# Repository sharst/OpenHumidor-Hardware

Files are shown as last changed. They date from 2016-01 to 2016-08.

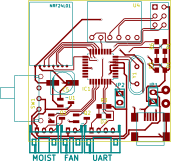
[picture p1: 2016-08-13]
CircuitBoards/openhum6-mega/gerber/front.png

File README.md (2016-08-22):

# OpenHumidor-Hardware
KiCad files of the OpenHumidor sensor PCB.
Files for 3D-printed humidifier parts, enclosures of the sensor board, etc.

Copyright 2016 Simon Harst

These files are licenced under the GPL v3 Licence, see LICENCE file.

The sensor PCB

I have included former versions of the PCB in separate folders. 

Versions 2 and 3 were created using the free version of EAGLE. Since version 4, boards are created with KICAD. 

## Ordering PCBs
The current version of the board is v0.6-mega. I'm currently testing all functions but minor bugs might still occur. If you're interested in trying out this project, you should consider contacting me.

So far, I have only ordered with two companies: 
* [PCB-pool](www.pcb-pool.de), located in Germany, the cheapest option takes about 2 weeks incl. shipping, you can directly upload the .kicad_pcb-file. 
* [Seeed Studio](http://www.seeedstudio.com/service/index.php?r=pcb), located in China and a lot cheaper (~14Euros for 10 pcbs). Takes about a month including shipping. You need to upload the .zip-file that's included in the gerber/ folder.

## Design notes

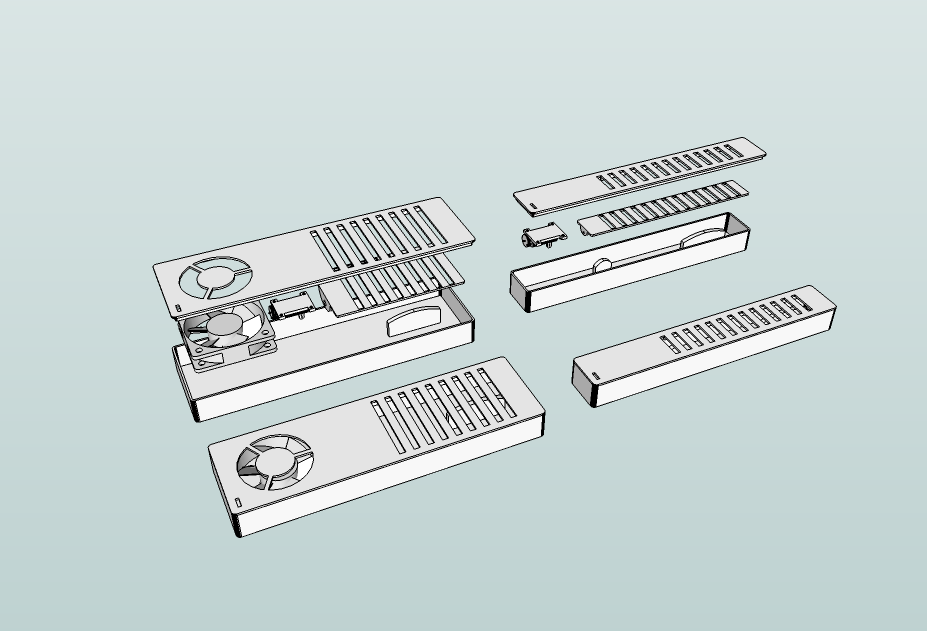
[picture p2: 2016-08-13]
Humidifier/humidifier_3dprint_overview.png

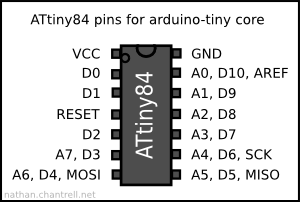
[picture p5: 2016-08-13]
datasheets_pinouts/attiny84-arduinocore.png

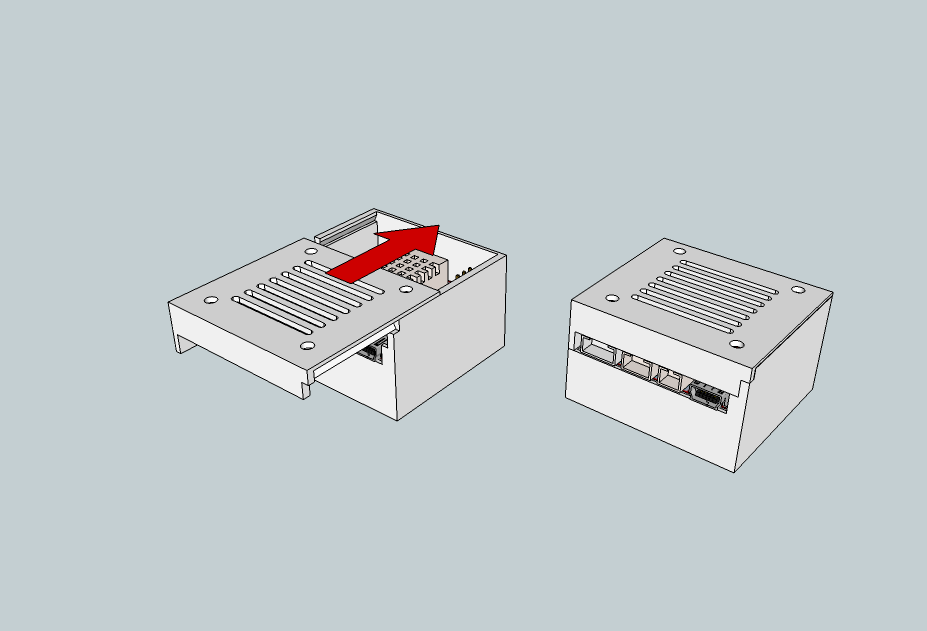
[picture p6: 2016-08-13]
BoardEnclosure/board-enclosure.png

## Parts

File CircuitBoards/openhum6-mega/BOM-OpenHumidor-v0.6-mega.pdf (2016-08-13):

(Akku BST-38) | 3.85 | 1 | 3.85 | ebay

## BOM OpenHumidor v0.6-mega

Piece Number | Decription | Price / unit | Amount | Total Price | Source | order number | Alternative Source | Alt. order # | Alt. Price | Notes
IC1 | ATMEGA328P-A | 3.2 | 1 | 3.2 | reichelt | ATMEGA 328P-AU | aliexpress | ATMEGA328 | 1.07
R1 | 470 O | 0.103 | 1 | 0.103 | reichelt | SMD-0805 470 | farnell | 9333258
R2 | 2k | 0.103 | 2 | 0.206 | reichelt N/A | | farnell | 9332766
R3 | 1k | 0.103 | 1 | 0.103 | reichelt | SMD-0805 1,00K | farnell | 9332383
R6 | 100 O | 0.103 | 1 | 0.103 | reichelt | SMD-0805 100
U1 | MCP1700 | 0.386 | 1 | 0.386 | farnell | 1296592 | reichelt | MCP 1703-3302CB
U2 | MCP73831 | 0.563 | 1 | 0.563 | farnell | 1840935
U3 | Nrf24L01 Mini | 1.16 | 1 | 1.16 | ebay | Nrf24L01 Mini
U4 | BME280 | 4.5 | 1 | 4.5 | ebay | 282083076305 | ebay (from Germany | 17224747660 | | BMP280 does NOT work (has no humidity sensor)
D1 | LED RED | 0.08 | 1 | 0.08 | reichelt | SMD-LED 0805 RT | farnell | 2090236
D2 | Fast switching diode | 0.04 | 1 | 0.04 | reichelt | TS 4148-0805
D3 | LED BLUE | 0.194 | 1 | 0.194 | reichelt | SMD-LED 0805 BL | farnell | 2217974
C1, C2 | 4.7uF | 0.05 | 2 | 0.1 | reichelt | X5R-G0805 4,7 | farnell | 2426962
C3 | 100nF | 0.04 | 1 | 0.04 | reichelt | X7R-G0805 100N
C5 | 100uF | 0.2 | 1 | 0.2 | reichelt | VF 100/6,3 P-C
C4, C6 | 22pF | 0.04 | 2 | 0.08 | reichelt | NPO-G0805 22P | farnell | 2497023
Q1, Q2 | 2n7002 JFET | 0.04 | 2 | 0.08 | reichelt | 2N 7002 SMD
CON1 | Mini USB Connector | 0.27 | 1 | 0.27 | reichelt | USB BWM SMD | farnell | 1125348
P1 | Header 6-PIN | 0.13 | 1 | 0.13 | reichelt | MPE 087-2-006 | farnell | 1622578
P3 | JST-PH4 | 0.139 | 1 | 0.139 | farnell | 9492488
P4 | JST-PH3 | 0.152 | 2 | 0.304 | farnell | 9491910
P5 | JST-PH2 | 0.11 | 1 | 0.11 | farnell | 9491902
SW1 | ON/OFF-Switch | 0.109 | 1 | 0.109 | ebay | SS12F21
Y1 | Quarz 16MHz | 0.28 | 1 | 0.28 | reichelt | 16,0000-HC49U-S | farnell | 2509297
Board Manufacture | | 0.99 | 1 | 0.99 | seeedstudio
JP1, JP2 | Jumper
| | | Total | 13.47

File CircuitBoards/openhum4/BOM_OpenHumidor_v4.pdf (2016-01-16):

(Akku BST-38) | ebay | 3.9 | 0 | 3.9

## BOM OpenHumidor v4

Piece Number | Decription | Source | Price / unit | Amount | Total Price | order number | alternative
IC1 | ATTINY84-SSU | reichelt | 1.5 | 1 | 1.5 | ATTINY84-SSU
IC2 | DHT22 | ebay | 2.88 | 1 | 2.88
R1 | 470 O | reichelt | 0.103 | 1 | 0.103 | SMD 1/4W 470
R2 | 2k | reichelt | 0.103 | 2 | 0.206 | SMD 1/4W 2,0K
R6, R7 | 100 O | reichelt | 0.103 | 2 | 0.206 | SMD 1/4W 100
U1 | MCP1700 | farnell | 0.386 | 1 | 0.386 | 1296592
U2 | MCP73831 | farnell | 0.563 | 1 | 0.563 | 1840935
U3 | Nrf24L01 Mini | ebay | 0.82 | 1 | 0.82
D1 | LED GREEN | farnell | 0.0748 | 1 | 0.0748 | 2099247
D3 | LED BLUE | farnell | 0.194 | 1 | 0.194 | 2217976
C1, C2 | 4.7uF | farnell | 0.0441 | 2 | 0.0882 | 9227938
C3, C4 | 100uF | farnell | 0.78 | 1 | 0.78 | 2354127
Q1, Q2 | 2n7002 JFET | farnell | 0.051 | 2 | 0.102 | 1764535
CON1 | Mini USB Connector | reichelt | 0.27 | 1 | 0.27 | USB BWM SMD | Farnell 1125348
P1 | Header 6-PIN | reichelt | 0.13 | 1 | 0.13 | MPE 087-2-006 | Farnell 1622578 oder 10stck 1022231
P3, P4 | JST-PH3 | farnell | 0.152 | 2 | 0.304 | 9491910
P5 | JST-PH2 | farnell | 0.11 | 1 | 0.11 | 9491902
Board Manufacture | | seeedstudio | 0.99 | 1 | 0.99
| | | | Gesamt | 9.707

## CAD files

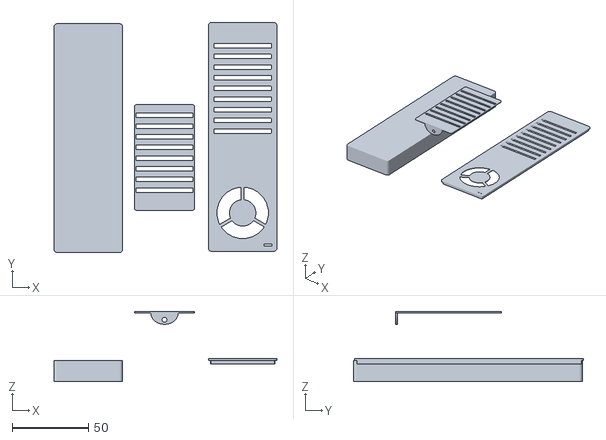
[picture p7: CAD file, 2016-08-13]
Humidifier/humidifier_3dprint_large.stl
146.2 x 150.8 x 46.1

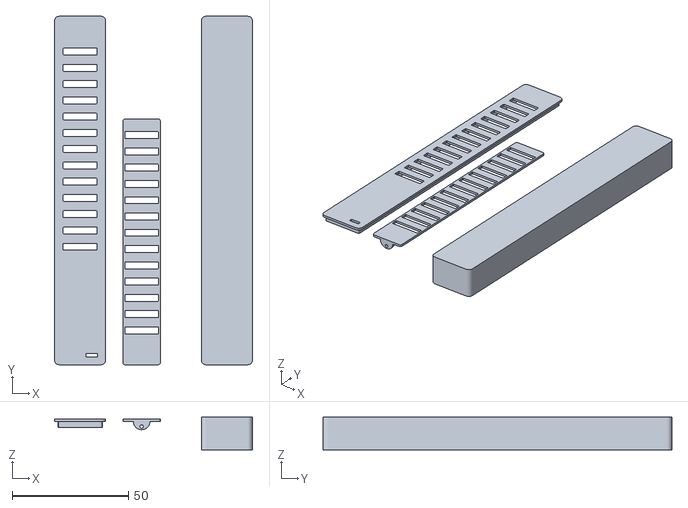
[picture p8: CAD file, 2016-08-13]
Humidifier/humidifier_3dprint_small.stl
85.2 x 150.0 x 14.0

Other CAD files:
BaseStation/BaseStation.skp
BoardEnclosure/board-enclosure.skp
BoardEnclosure/board-enclosure_v06.skp
Humidifier/humidifier_fabtools.skp
Humidifier/humidifier_fabtools_stepper.skp
Humidifier/humidifiers_3dprint.skp

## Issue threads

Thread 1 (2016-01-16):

Fan mount on enclosure

sharst, 2016-01-16:
The enclosure should have a mount for a 5V, 40mm fan that can be enabled before checking the humidity.

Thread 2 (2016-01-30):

Q1 drain pin isn't pulled up nicely when gate is pulled low

sharst, 2016-01-30:

sharst, 2016-01-30:
This seems to be related to the DHT22 since everything works on a board where the DHT isn't mounted

sharst, 2016-01-30:
Was a software bug: Since the DHT-Data pin is pulled high by hardware, sinks a lot of current when pulled low. This happened in enable_io(). Fixed.

Closed 2016-01-30.

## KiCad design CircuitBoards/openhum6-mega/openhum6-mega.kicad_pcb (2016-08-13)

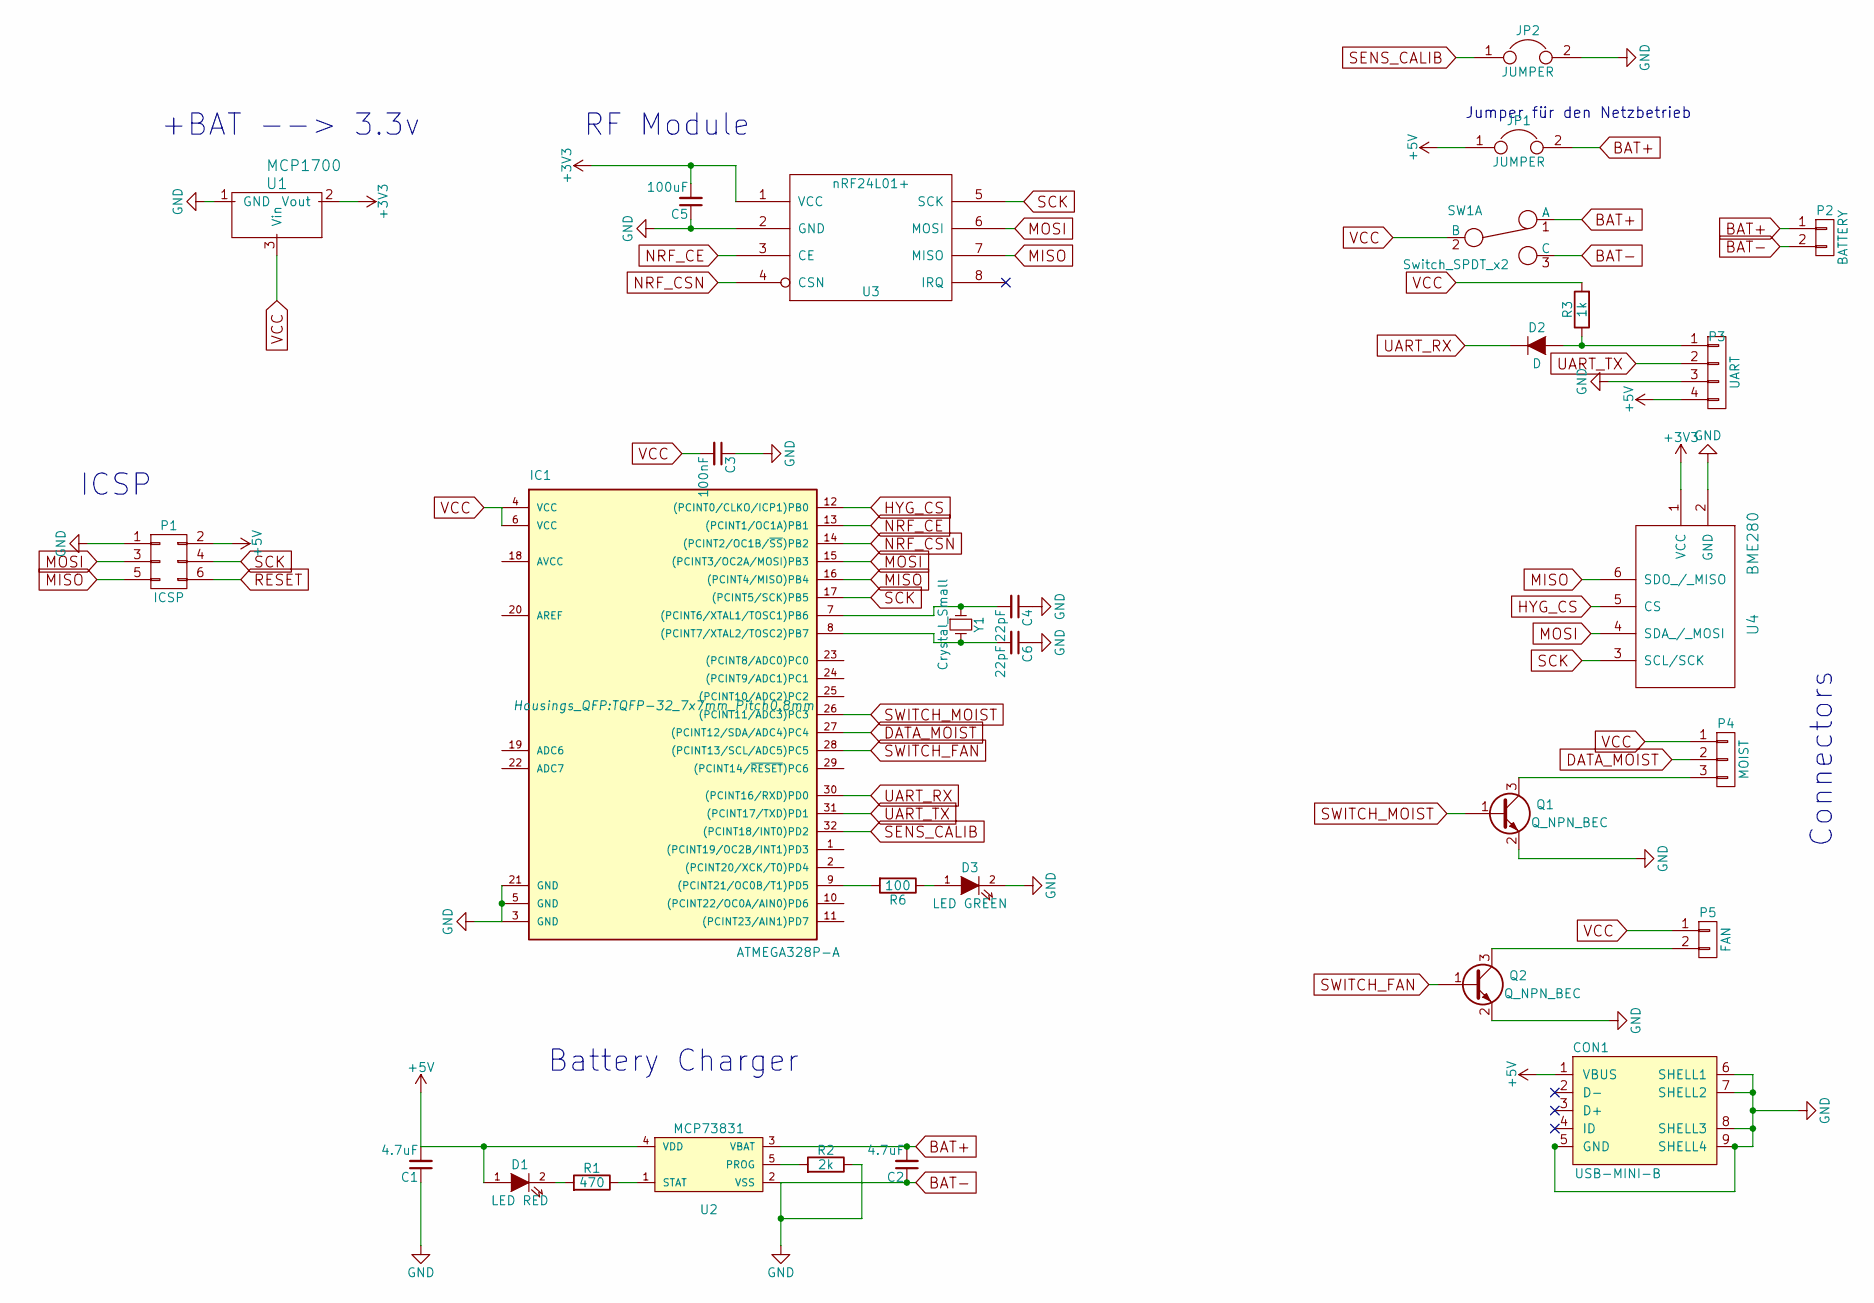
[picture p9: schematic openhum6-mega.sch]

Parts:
C1, C2: 4.7uF; R_0805_HandSoldering
C3: 100nF; R_0805_HandSoldering
C4, C6: 22pF; R_0805_HandSoldering
C5: 100uF; c_elec_6.3x5.3
CON1: USB-MINI-B; USB_Mini-B
D1: LED RED; R_0805_HandSoldering
D2: D; R_0805_HandSoldering
D3: LED GREEN; R_0805_HandSoldering
IC1: ATMEGA328P-A; TQFP-32_7x7mm_Pitch0.8mm
JP1, JP2: JUMPER; pin_strip_2
P1: ICSP; 2x3_pin_header
P2: BATTERY; solderpad2x
P3: UART; s4b-ph-kl
P4: MOIST; s3b-ph-kl
P5: FAN; s2b-ph-kl
Q1, Q2: Q_NPN_BEC; SOT-23_Handsoldering
R1: 470; R_0805_HandSoldering
R2: 2k; R_0805_HandSoldering
R3: 1k; R_0805_HandSoldering
R6: 100; R_0805_HandSoldering
SW1: Switch_SPDT_x2; SS12F23
U1: MCP1700; SOT-23_Handsoldering
U2: MCP73831; SOT-23-5_handsoldering
U3: nRF24L01+; nrf24l01_mini
U4: BME280; BMP280
Y1: Crystal_Small; Crystal_HC49-U_Vertical

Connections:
+3V3: C5.2, U1.2 (Vout), U3.1 (VCC), U4.1 (VCC)
+5V: C1.2, CON1.1 (VBUS), D1.1 (A), JP1.1, P1.2, P3.4, U2.4 (VDD)
BAT+: C2.2, JP1.2, P2.1, SW1.1 (A), U2.3 (VBAT)
BAT-: C1.1, C2.1, C3.1, C4.1, C5.1, C6.1, CON1.5 (GND), CON1.6 (SHELL1), CON1.7 (SHELL2), CON1.8 (SHELL3), CON1.9 (SHELL4), D3.2 (K), IC1.3 (GND), IC1.5 (GND), IC1.21 (GND), JP2.2, P1.1, P2.2, P3.3, Q1.2 (E), Q2.2 (E), R2.1, SW1.3 (C), U1.1 (GND), U2.2 (VSS), U3.2 (GND), U4.2 (GND)
DATA_MOIST: IC1.27 ((PCINT12/SDA/ADC4)PC4), P4.2
HYG_CS: IC1.12 ((PCINT0/CLKO/ICP1)PB0), U4.5 (CS)
MISO: IC1.16 ((PCINT4/MISO)PB4), P1.5, U3.7 (MISO), U4.6 (SDO_/_MISO)
MOSI: IC1.15 ((PCINT3/OC2A/MOSI)PB3), P1.3, U3.6 (MOSI), U4.4 (SDA_/_MOSI)
NRF_CE: IC1.13 ((PCINT1/OC1A)PB1), U3.3 (CE)
NRF_CSN: IC1.14 ((PCINT2/OC1B/~SS~)PB2), U3.4 (CSN)
unnamed: C4.2, IC1.7 ((PCINT6/XTAL1/TOSC1)PB6), Y1.1
unnamed: C6.2, IC1.8 ((PCINT7/XTAL2/TOSC2)PB7), Y1.2
unnamed: D1.2 (K), R1.2
unnamed: D2.2 (A), P3.1, R3.1
unnamed: D3.1 (A), R6.1
unnamed: IC1.9 ((PCINT21/OC0B/T1)PD5), R6.2
unnamed: P4.3, Q1.3 (C)
unnamed: P5.2, Q2.3 (C)
unnamed: R1.1, U2.1 (STAT)
unnamed: R2.2, U2.5 (PROG)
RESET: IC1.29 ((PCINT14/~RESET~)PC6), P1.6
SCK: IC1.17 ((PCINT5/SCK)PB5), P1.4, U3.5 (SCK), U4.3 (SCL/SCK)
SENS_CALIB: IC1.32 ((PCINT18/INT0)PD2), JP2.1
SWITCH_FAN: IC1.28 ((PCINT13/SCL/ADC5)PC5), Q2.1 (B)
SWITCH_MOIST: IC1.26 ((PCINT11/ADC3)PC3), Q1.1 (B)
UART_RX: D2.1 (K), IC1.30 ((PCINT16/RXD)PD0)
UART_TX: IC1.31 ((PCINT17/TXD)PD1), P3.2
VCC: C3.2, IC1.4 (VCC), IC1.6 (VCC), P4.1, P5.1, R3.2, SW1.2 (B), U1.3 (Vin)

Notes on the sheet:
Battery Charger
ICSP
+BAT --> 3.3v
RF Module
Connectors
Jumper für den Netzbetrieb

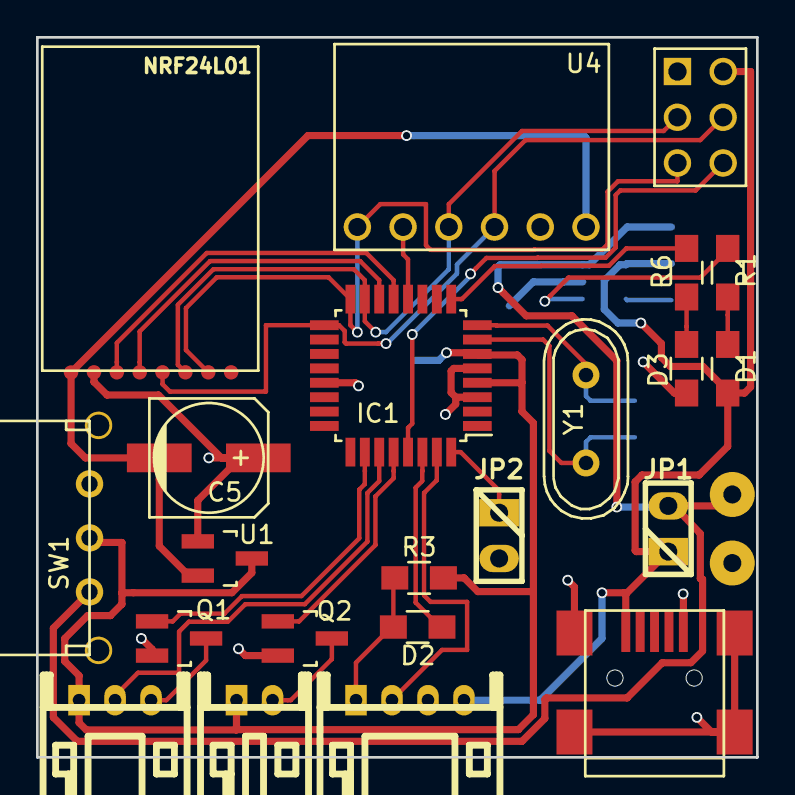
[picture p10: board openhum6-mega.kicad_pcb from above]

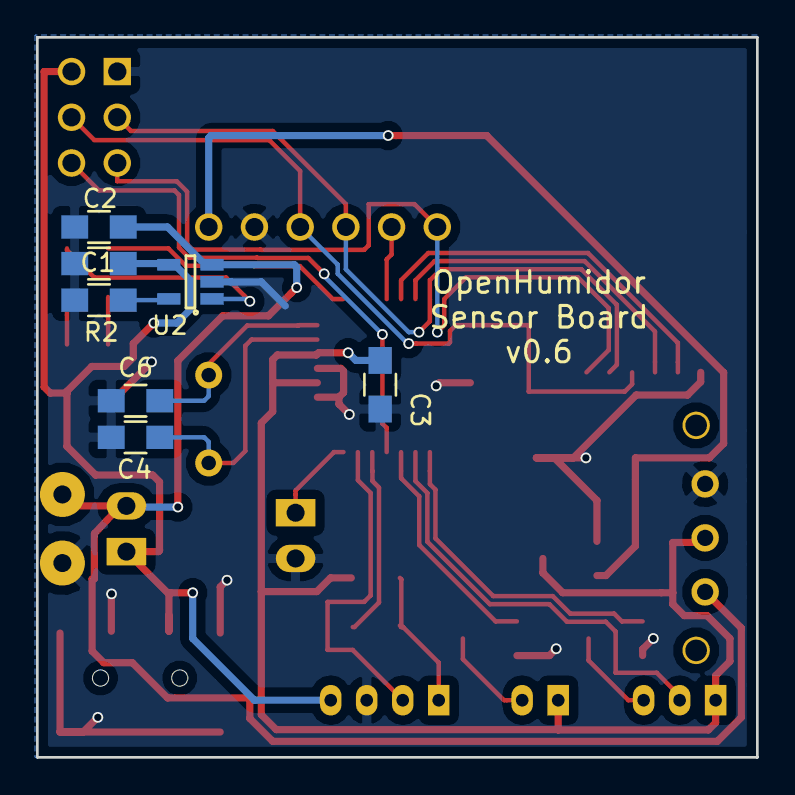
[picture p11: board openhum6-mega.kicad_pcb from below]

Board: 2 copper layers, 40.0 x 40.0 mm, 27 parts (7 on the bottom side), 24 nets.

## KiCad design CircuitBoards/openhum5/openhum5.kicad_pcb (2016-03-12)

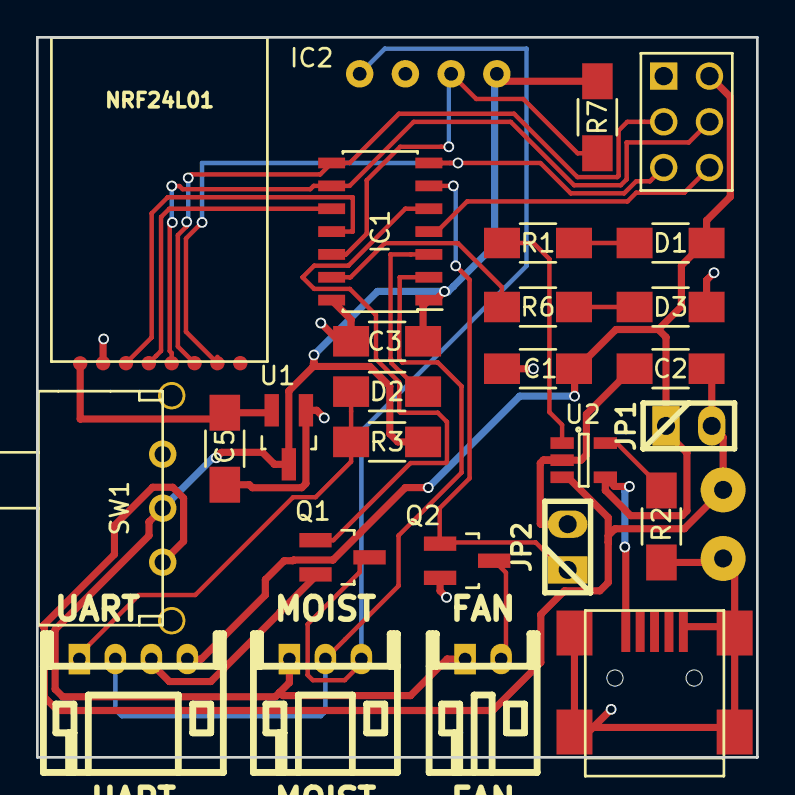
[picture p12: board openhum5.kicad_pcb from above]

Board: 2 copper layers, 40.0 x 40.0 mm, 28 parts (0 on the bottom side), 24 nets.

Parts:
C1, C2: 4.7uF; R_1206_HandSoldering
C3, C5: 100uF; R_1206_HandSoldering
CON1: USB-MINI-B; USB_Mini-B
D1: LED RED; R_1206_HandSoldering
D2: D; R_1206_HandSoldering
D3: LED GREEN; R_1206_HandSoldering
FAN: FAN; s2b-ph-kl
IC1: ATTINY84A-SS; SOIC-14_3.9x8.7mm_Pitch1.27mm
IC2: DHT22
JP1, JP2: JUMPER; pin_strip_2
MOIST: MOIST; s3b-ph-kl
P1: ICSP; 2x3_pin_header
P2: BATTERY; solderpad2x
Q1, Q2: Q_NPN_BEC; SOT-23_Handsoldering
R1: 470; R_1206_HandSoldering
R2: 2k; R_1206_HandSoldering
R3: 1k; R_1206_HandSoldering
R6, R7: 100; R_1206_HandSoldering
SW1: Switch_SPDT_x2; SS12F23
U1: MCP1700; SOT-23_Handsoldering
U2: MCP73831; SOT-23-5_handsoldering
U3: nRF24L01+; nrf24l01_mini
UART: UART; s4b-ph-kl

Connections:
+3V3: C5.2, U1.2, U3.1
+5V: C1.2, CON1.1, D1.1, JP1.1, P1.2, U2.4, UART.4
BAT+: C2.2, JP1.2, P2.1, SW1.1, U2.3
BAT-: C1.1, C2.1, C3.2, C5.1, CON1.5, CON1.6, D3.2, IC1.14, JP2.2, P1.1, P2.2, Q1.2, Q2.2, R2.1, SW1.3, U1.1, U2.2, U3.2, UART.3
DATA_HYGRO: IC1.12, IC2.2, R7.1
DATA_MOIST: IC1.2, MOIST.2, UART.2
MISO: IC1.7, P1.5, U3.7
MOSI: IC1.8, P1.3, U3.6
NRF_CE: IC1.11, U3.3
NRF_CSN: IC1.10, U3.4
unnamed: D1.2, R1.2
unnamed: D2.2, R3.1, UART.1
unnamed: D3.1, R6.1
unnamed: IC1.13, R6.2
unnamed: IC2.4, MOIST.3, Q1.3
unnamed: FAN.2, Q2.3
unnamed: R1.1, U2.1
unnamed: R2.2, U2.5
RESET: IC1.4, P1.6
SCK: IC1.9, P1.4, U3.5
SENS_CALIB: IC1.6, JP2.1, Q2.1
SWITCH_MOIST: IC1.5, Q1.1
UART_RX: D2.1, IC1.3
VCC: C3.1, FAN.1, IC1.1, IC2.1, MOIST.1, R3.2, R7.2, SW1.2, U1.3

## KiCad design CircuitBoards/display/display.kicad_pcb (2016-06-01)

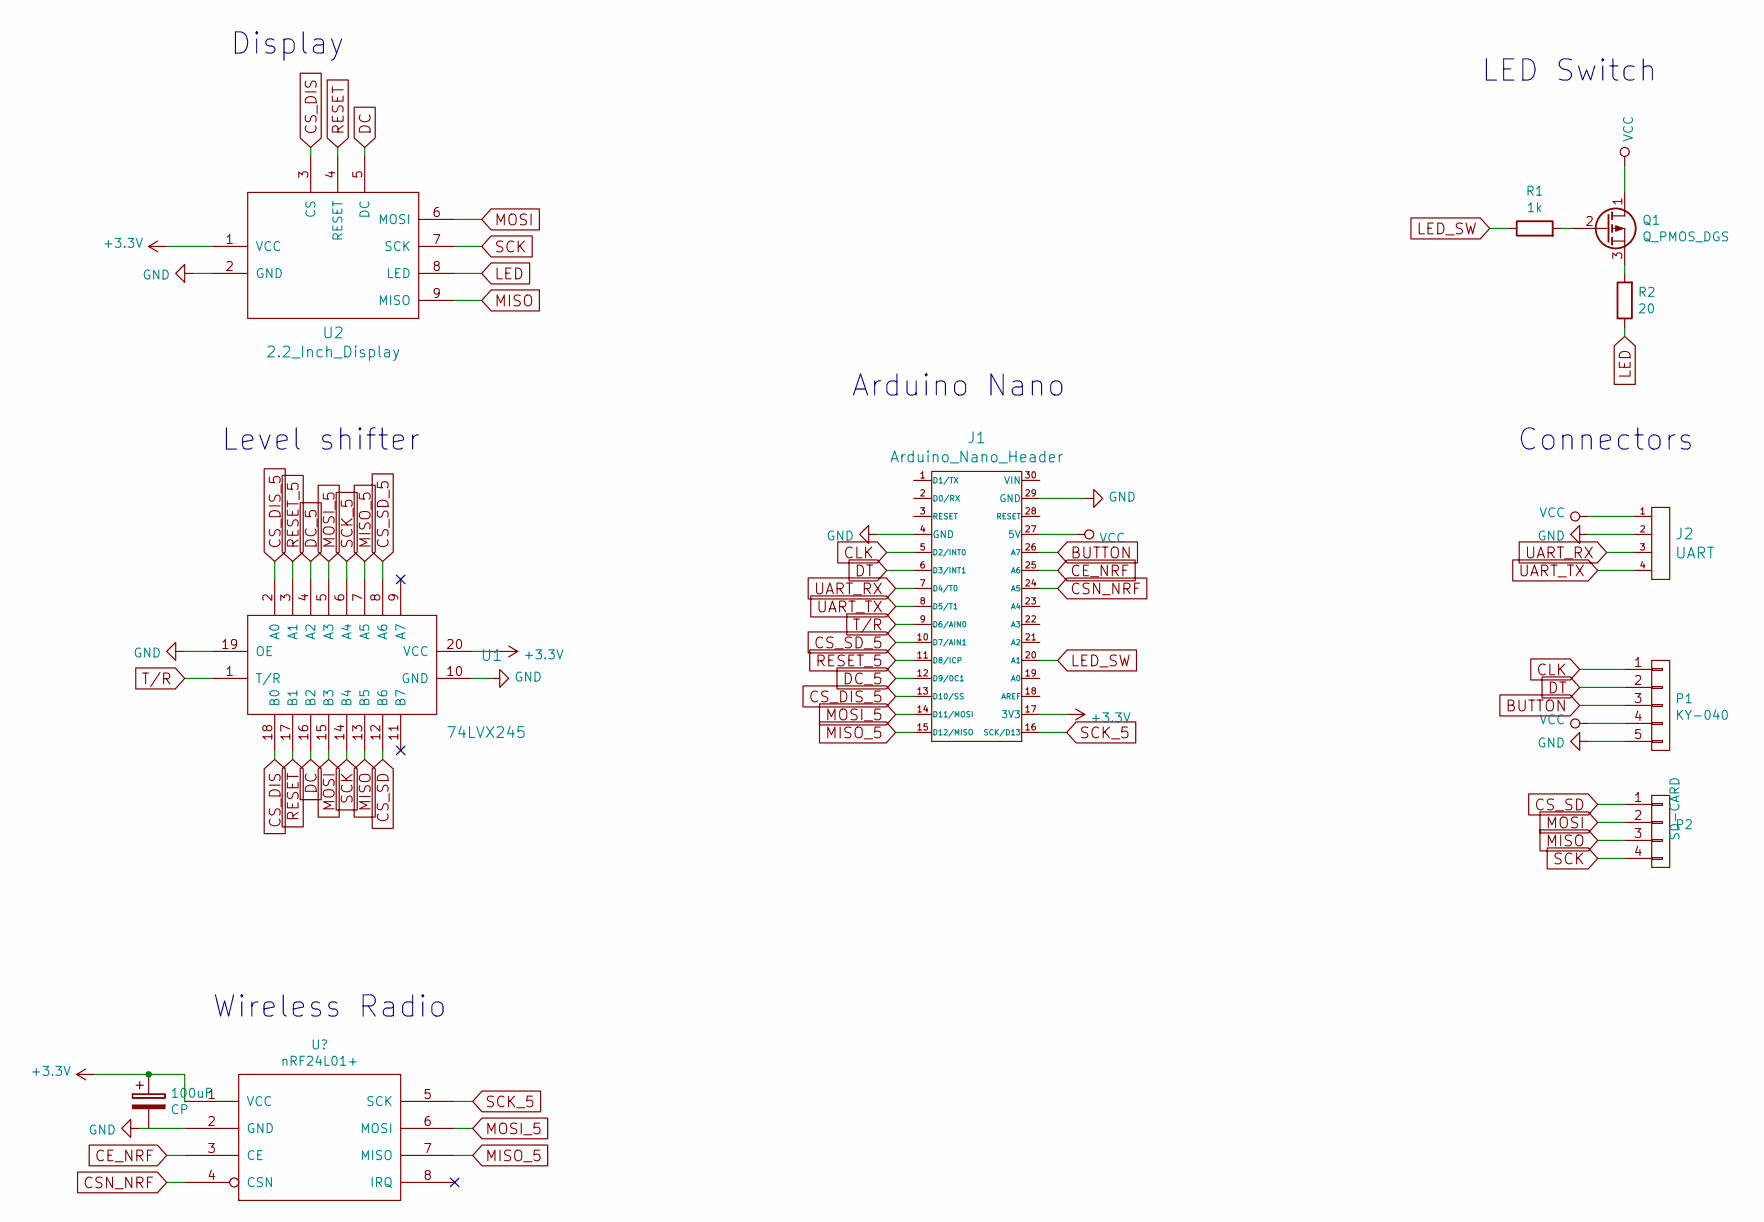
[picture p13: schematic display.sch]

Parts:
100uF: CP
J1: Arduino_Nano_Header; arduino_nano_header
J2: UART; b4b-ph-kl
P1: KY-040; b5b-ph-kl
P2: SD-CARD; b4b-ph-kl
Q1: Q_PMOS_DGS; SOT-23_Handsoldering
R1: 1k; R_1206_HandSoldering
R2: 20; R_1206_HandSoldering
U1: 74LVX245; TSSOP20
U2: 2.2_Inch_Display; 2_2inch_display

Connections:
+3V3: 100uF.1, J1.17 (3V3), U1.20 (VCC), U2.1 (VCC)
BUTTON: J1.26 (A7), P1.3
CLK: J1.5 (D2/INT0), P1.1
CS_DIS: U1.18 (B0), U2.3 (CS)
CS_DIS_5: J1.13 (D10/SS), U1.2 (A0)
CS_SD: P2.1, U1.12 (B6)
CS_SD_5: J1.10 (D7/AIN1), U1.8 (A6)
DC: U1.16 (B2), U2.5 (DC)
DC_5: J1.12 (D9/0C1), U1.4 (A2)
DT: J1.6 (D3/INT1), P1.2
GND: J1.4 (GND), J1.29 (GND), J2.2, P1.5, U1.10 (GND), U1.19 (OE), U2.2 (GND)
LED: R2.1, U2.8 (LED)
LED_SW: J1.20 (A1), R1.1
MISO: P2.3, U1.13 (B5), U2.9 (MISO)
MISO_5: J1.15 (D12/MISO), U1.7 (A5)
MOSI: P2.2, U1.15 (B3), U2.6 (MOSI)
MOSI_5: J1.14 (D11/MOSI), U1.5 (A3)
unnamed: Q1.2 (G), R1.2
unnamed: Q1.3 (S), R2.2
RESET: U1.17 (B1), U2.4 (RESET)
RESET_5: J1.11 (D8/ICP), U1.3 (A1)
SCK: P2.4, U1.14 (B4), U2.7 (SCK)
SCK_5: J1.16 (SCK/D13), U1.6 (A4)
T/R: J1.9 (D6/AIN0), U1.1 (T/R)
UART_RX: J1.7 (D4/T0), J2.3
UART_TX: J1.8 (D5/T1), J2.4
VCC: J1.27 (5V), J2.1, P1.4, Q1.1 (D)

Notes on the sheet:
Arduino Nano
Display
Level shifter
LED Switch
Connectors
Wireless Radio

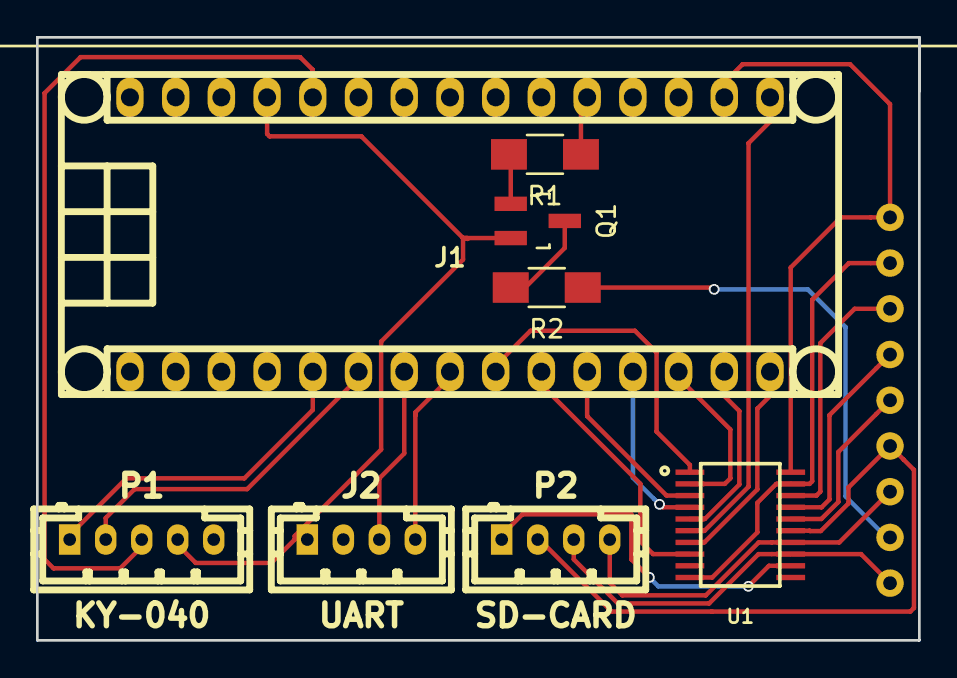
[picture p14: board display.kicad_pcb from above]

Board: 2 copper layers, 49.0 x 33.5 mm, 9 parts (0 on the bottom side), 27 nets.

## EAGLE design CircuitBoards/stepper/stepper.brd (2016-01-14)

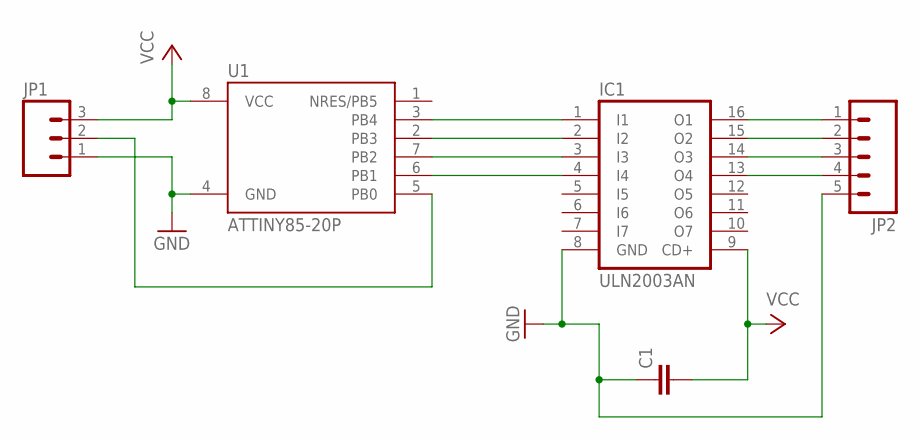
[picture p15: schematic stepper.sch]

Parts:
C1: C-EU025-025X050; C025-025X050
IC1: ULN2003AN; DIL16
JP1: M03JST-PTH; JST-3-PTH
JP2: M05PTH_LONGPADS; 1X05_LONGPADS
U1: ATTINY85-20P; PDIP08_300MIL

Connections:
GND: C1.1, IC1.8 (GND), JP1.1, JP2.5, U1.4 (GND)
unnamed: IC1.1 (I1), U1.3 (PB4)
unnamed: IC1.2 (I2), U1.2 (PB3)
unnamed: IC1.3 (I3), U1.7 (PB2)
unnamed: IC1.4 (I4), U1.6 (PB1)
unnamed: JP1.2, U1.5 (PB0)
unnamed: IC1.16 (O1), JP2.1
unnamed: IC1.15 (O2), JP2.2
unnamed: IC1.14 (O3), JP2.3
unnamed: IC1.13 (O4), JP2.4
VCC: C1.2, IC1.9 (CD+), JP1.3, U1.8 (VCC)

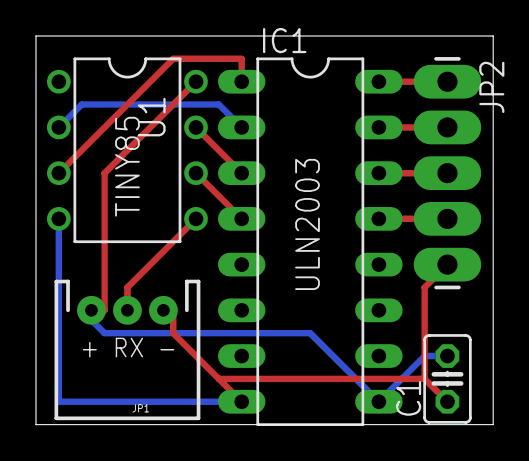
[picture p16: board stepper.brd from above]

Board: 2 copper layers, 25.4 x 21.6 mm, 5 parts (0 on the bottom side), 11 nets.

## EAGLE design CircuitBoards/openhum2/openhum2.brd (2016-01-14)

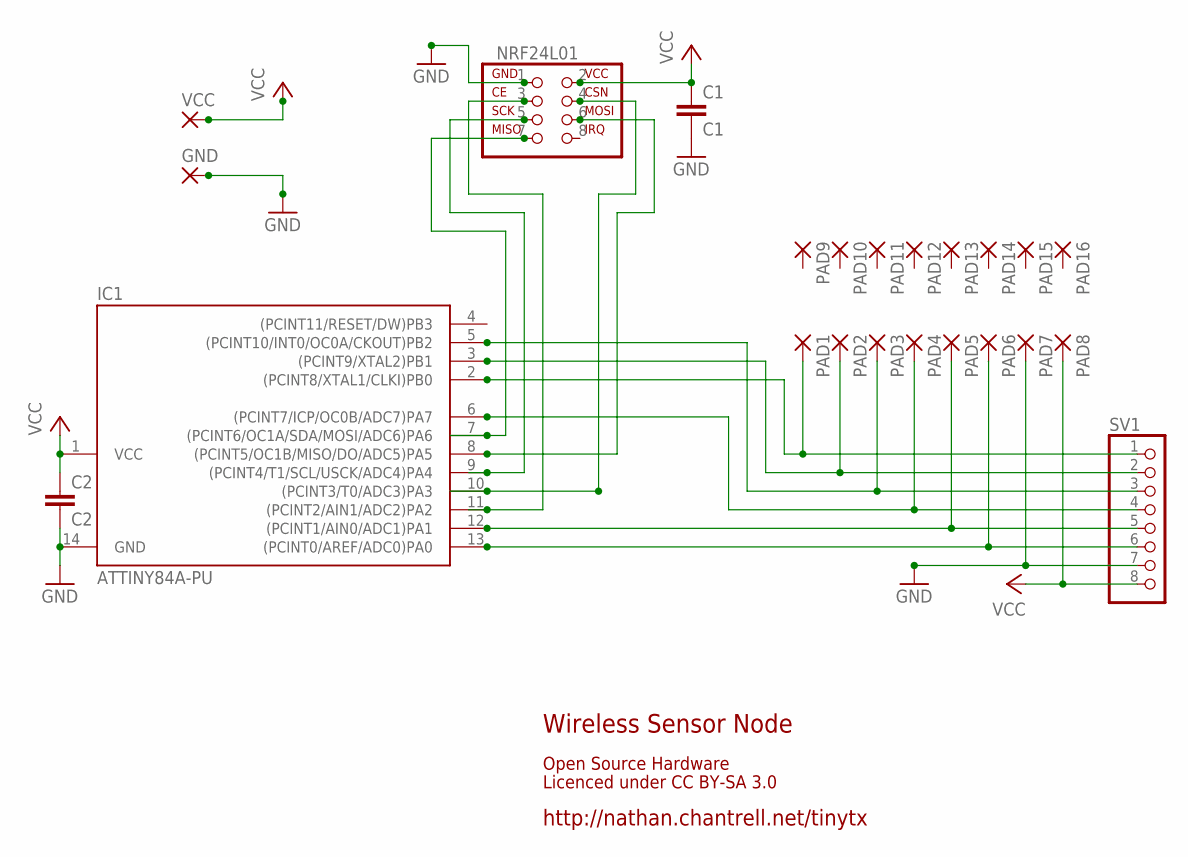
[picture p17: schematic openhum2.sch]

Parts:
C1: C1; C025-025X050
C2: C2; C025-025X050
GND: 2,15/1,0
IC1: ATTINY84A-PU; DIL14
NRF24L01: NRF24L01+
PAD1, PAD2, PAD3, PAD4, PAD5, PAD6, PAD7, PAD8, PAD9, PAD10, PAD11, PAD12, PAD13, PAD14, PAD15, PAD16: 1,6/0,9
SV1: PINHD-1X8; 1X08
VCC: 2,15/1,0

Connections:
GND: C1.2, C2.2, GND.1, IC1.14 (GND), NRF24L01.1, PAD7.1, SV1.7
unnamed: IC1.11 ((PCINT2/AIN1/ADC2)PA2), NRF24L01.3
unnamed: IC1.10 ((PCINT3/T0/ADC3)PA3), NRF24L01.4
unnamed: IC1.9 ((PCINT4/T1/SCL/USCK/ADC4)PA4), NRF24L01.5
unnamed: IC1.7 ((PCINT6/OC1A/SDA/MOSI/ADC6)PA6), NRF24L01.7
unnamed: IC1.5 ((PCINT10/INT0/OC0A/CKOUT)PB2), PAD3.1, SV1.3
unnamed: IC1.3 ((PCINT9/XTAL2)PB1), PAD2.1, SV1.2
unnamed: IC1.13 ((PCINT0/AREF/ADC0)PA0), PAD6.1, SV1.6
unnamed: IC1.12 ((PCINT1/AIN0/ADC1)PA1), PAD5.1, SV1.5
unnamed: IC1.8 ((PCINT5/OC1B/MISO/DO/ADC5)PA5), NRF24L01.6
unnamed: IC1.2 ((PCINT8/XTAL1/CLKI)PB0), PAD1.1, SV1.1
unnamed: IC1.6 ((PCINT7/ICP/OC0B/ADC7)PA7), PAD4.1, SV1.4
VCC: C1.1, C2.1, IC1.1 (VCC), NRF24L01.2, PAD8.1, SV1.8, VCC.1

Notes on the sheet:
http://nathan.chantrell.net/tinytx
Wireless Sensor Node
Licenced under CC BY-SA 3.0
Open Source Hardware

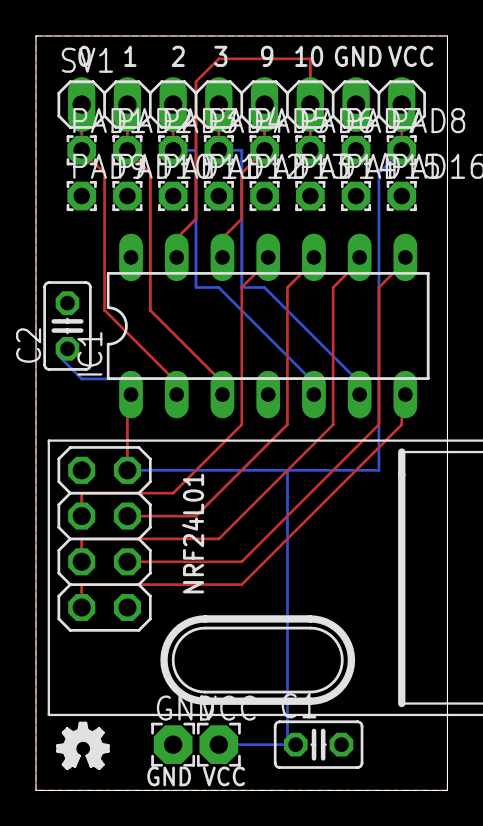
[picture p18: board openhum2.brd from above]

Board: 2 copper layers, 22.9 x 41.9 mm, 24 parts (0 on the bottom side), 13 nets.

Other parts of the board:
U$2: OSHW_FILLX100_NOTEXT

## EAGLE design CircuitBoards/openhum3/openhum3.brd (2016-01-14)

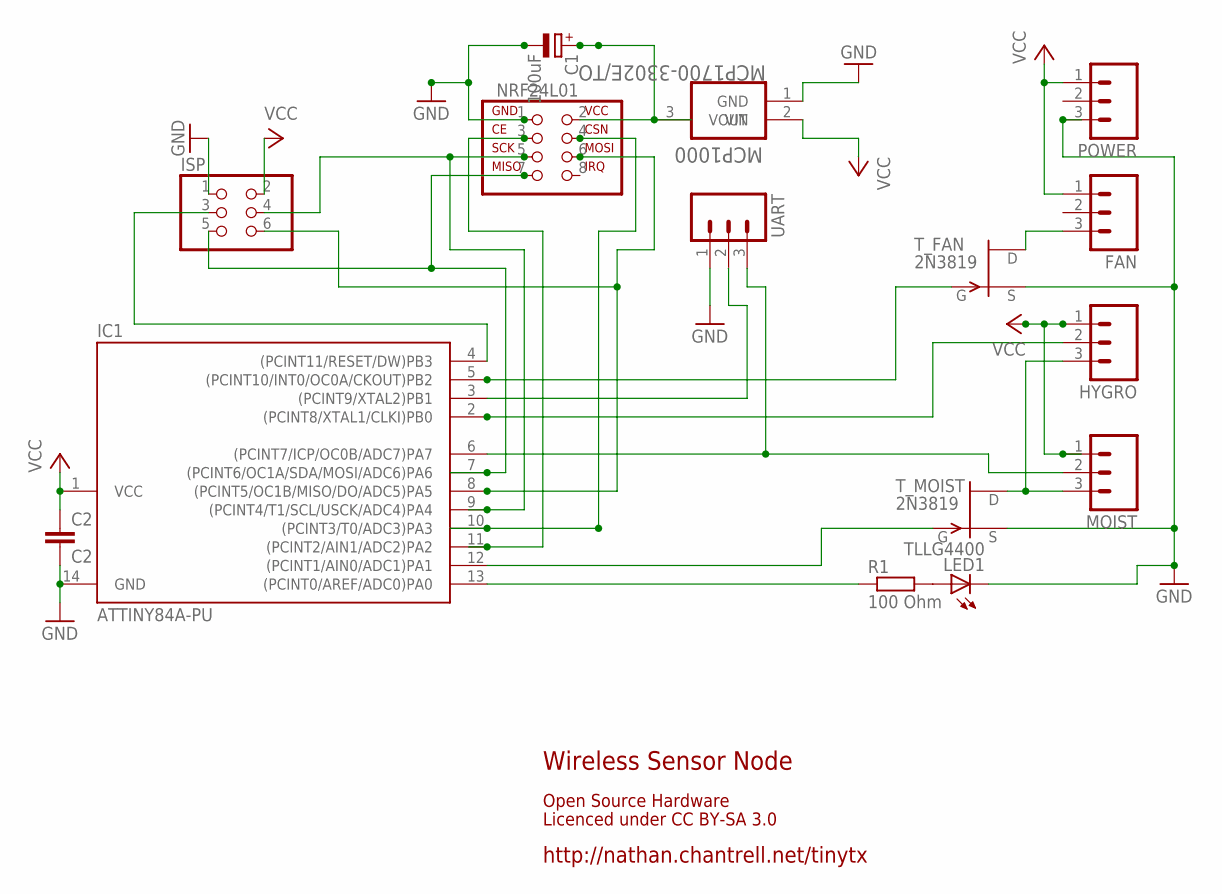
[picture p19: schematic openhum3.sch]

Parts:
C1: 100uF; E2,5-6
C2: C2; C025-025X050
FAN: M03JST-PTH; JST-3-PTH
HYGRO: M03JST-PTH; JST-3-PTH
IC1: ATTINY84A-PU; DIL14
ISP: PINHD-2X3; 2X03
LED1: TLLG4400; LED3MM
MCP1000: MCP1700-3302E/TO; TO127P254X495-3
MOIST: M03JST-PTH; JST-3-PTH
NRF24L01: NRF24L01+
POWER: M03JST-PTH; JST-3-PTH
R1: 100 Ohm; 0204/5
T_FAN: 2N3819; TO92
T_MOIST: 2N3819; TO92
UART: M03JST-PTH; JST-3-PTH

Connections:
GND: C1.-, C2.2, IC1.14 (GND), ISP.1, LED1.K (C), MCP1000.1 (GND), NRF24L01.1, POWER.3, T_FAN.3 (S), T_MOIST.3 (S), UART.1
unnamed: IC1.11 ((PCINT2/AIN1/ADC2)PA2), NRF24L01.3
unnamed: IC1.10 ((PCINT3/T0/ADC3)PA3), NRF24L01.4
unnamed: IC1.9 ((PCINT4/T1/SCL/USCK/ADC4)PA4), ISP.4, NRF24L01.5
unnamed: IC1.7 ((PCINT6/OC1A/SDA/MOSI/ADC6)PA6), ISP.5, NRF24L01.7
unnamed: FAN.3, T_FAN.1 (D)
unnamed: IC1.5 ((PCINT10/INT0/OC0A/CKOUT)PB2), T_FAN.2 (G)
unnamed: IC1.3 ((PCINT9/XTAL2)PB1), UART.2
unnamed: C1.+, MCP1000.3 (VOUT), NRF24L01.2
unnamed: IC1.12 ((PCINT1/AIN0/ADC1)PA1), T_MOIST.2 (G)
unnamed: IC1.13 ((PCINT0/AREF/ADC0)PA0), R1.1
unnamed: IC1.8 ((PCINT5/OC1B/MISO/DO/ADC5)PA5), ISP.6, NRF24L01.6
unnamed: HYGRO.2, IC1.2 ((PCINT8/XTAL1/CLKI)PB0)
unnamed: IC1.4 ((PCINT11/RESET/DW)PB3), ISP.3
unnamed: HYGRO.3, MOIST.3, T_MOIST.1 (D)
unnamed: IC1.6 ((PCINT7/ICP/OC0B/ADC7)PA7), MOIST.2, UART.3
unnamed: LED1.A, R1.2
VCC: C2.1, FAN.1, HYGRO.1, IC1.1 (VCC), ISP.2, MCP1000.2 (VIN), MOIST.1, POWER.1

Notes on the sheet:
http://nathan.chantrell.net/tinytx
Wireless Sensor Node
Licenced under CC BY-SA 3.0
Open Source Hardware

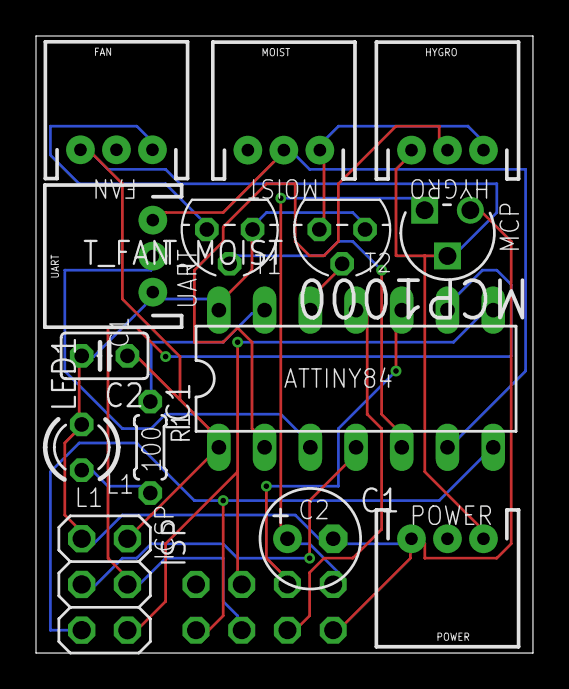
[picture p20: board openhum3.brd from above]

Board: 2 copper layers, 27.6 x 34.3 mm, 15 parts (1 on the bottom side), 18 nets.

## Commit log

2016-01-14 First commit of OpenHumidor PCB project
    [openhum2.brd, openhum2.sch, openhum3.brd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]
2016-01-16 Added BOM for OpenHumidor v4
2016-03-12 File version updates to board v5. Added board for new arduino nano base station
    [display.kicad_pcb, display.sch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]
2016-06-01 First production version of display PCB
    [display.kicad_pcb]
2016-08-13 Newest version of openhumidor board: v0.6
    [openhum6-mega.kicad_pcb, openhum6-mega.sch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]
2016-08-13 Add production drawings of PCB
2016-08-13 First STL version of humidifiers.
    [humidifier_large.stl, humidifier_small.stl]
2016-08-13 Reorganized repository; added sketchup and STL files + lots of documentation
    [BaseStation.skp, board-enclosure.skp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]
2016-08-22 Added gaps for printing, added battery pack
    [board-enclosure_v06.skp]

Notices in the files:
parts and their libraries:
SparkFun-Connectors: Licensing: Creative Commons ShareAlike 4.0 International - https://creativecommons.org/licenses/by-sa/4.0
